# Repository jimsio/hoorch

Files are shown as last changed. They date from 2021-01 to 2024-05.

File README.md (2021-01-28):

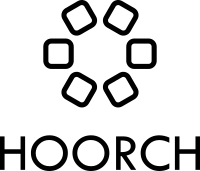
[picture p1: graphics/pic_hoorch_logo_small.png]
HOORCH Logo


an educational multimedia box

HOORCH is a multimedia box for primary school students. HOORCH is a dialect saying that means something like "listen up!".
It consists of a Raspberry Pi 3A+ , 6 RFID-Readers, a microphone, speakers and several LEDs and buttons. It is housed in a laser cutted box with a transparent board top.
We currently have 6 games:
* a storytelling game, where kids can record stories which are then stored for their specific character
* a calculating game
* a game for learning english animal names
* an animal voice guessing game
* an animal orchestra game for learning the animal voices
* a game for learning the parts of a modern instrumental song (e.g. bass line, hi-hat, snare, kick, melody)

Folders:
* . : python program, installation file (installer.sh), 
* [data](data): audio files
* [pcb](pcb): schematics, made with KiCad
* [graphics](graphics): laser cutter files for box, figures. vinylcutter files for cards, graphic files for animal stickers
* [docs](docs): documentation

HOORCH was developed at the University for Teacher Training (PH Wien) in Vienna, Austria.

Also visit our website:
(http://hoorch.phwien.ac.at)

# Installation

see [docs](docs)

# License

Licenced under the CC-BY-NC-SA 4.0 license

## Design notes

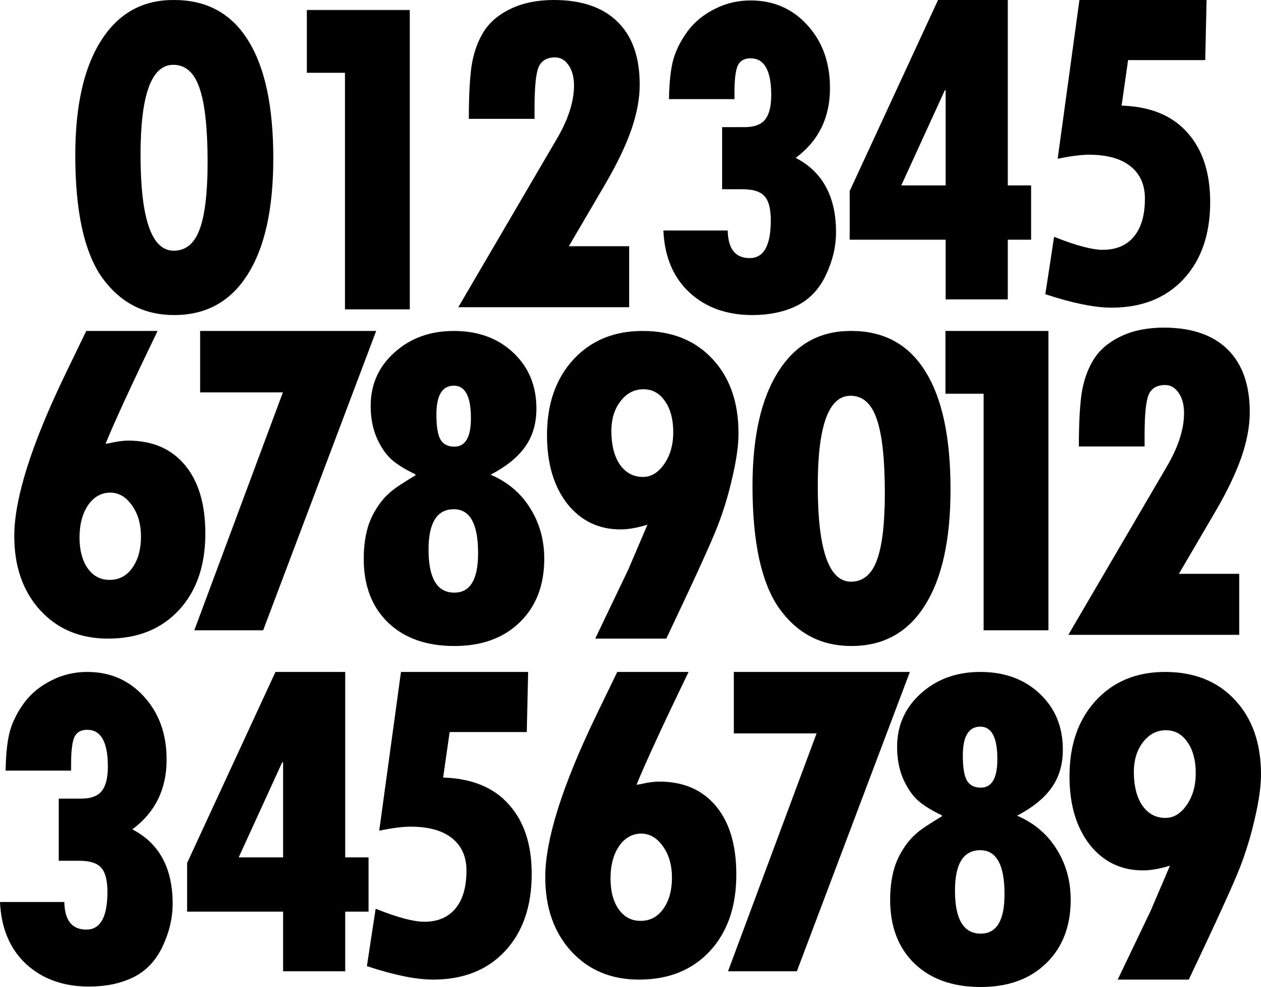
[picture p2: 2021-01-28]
graphics/vinyl_numbers.png

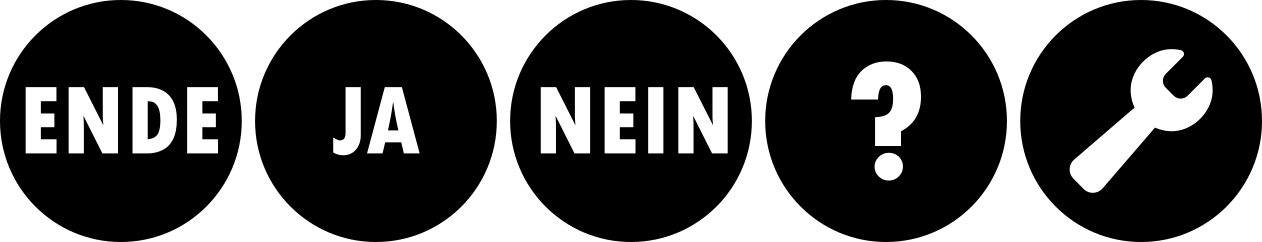
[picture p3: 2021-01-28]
graphics/vinyl_stickers.png

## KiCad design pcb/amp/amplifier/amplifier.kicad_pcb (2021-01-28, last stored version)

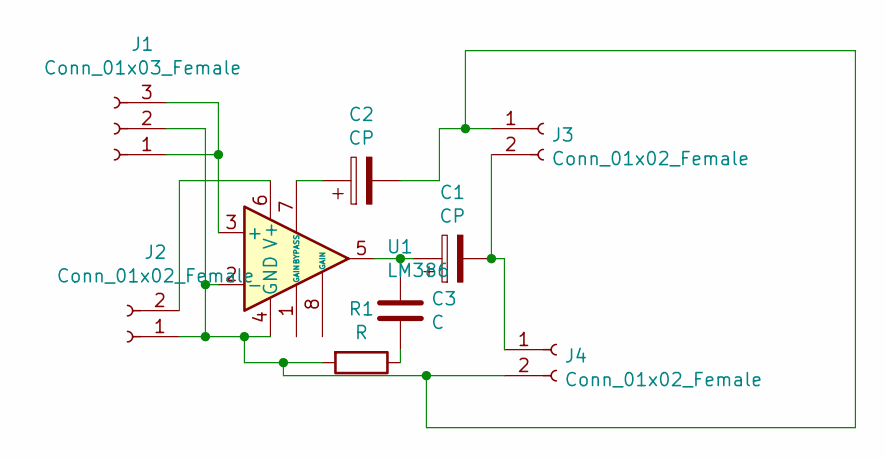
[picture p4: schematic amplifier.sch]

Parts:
C1: CP; CP_Radial_D10.0mm_P3.80mm
C2: CP; CP_Radial_D5.0mm_P2.50mm
C3: C; C_Disc_D4.3mm_W1.9mm_P5.00mm
J1: Conn_01x03_Female; PinHeader_1x03_P2.54mm_Vertical
J2, J3, J4: Conn_01x02_Female; PinHeader_1x02_P2.54mm_Vertical
R1: R; R_Axial_DIN0207_L6.3mm_D2.5mm_P10.16mm_Horizontal
U1: LM386; DIP-8_W7.62mm

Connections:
unnamed: C1.1, C3.1, U1.5
unnamed: C1.2, J3.2, J4.1
unnamed: C2.1, U1.7 (BYPASS)
unnamed: C2.2, J1.2, J2.1, J3.1, J4.2, R1.2, U1.2 (-), U1.4 (GND)
unnamed: C3.2, R1.1
unnamed: J1.1, J1.3, U1.3 (+)
unnamed: J2.2, U1.6 (V+)

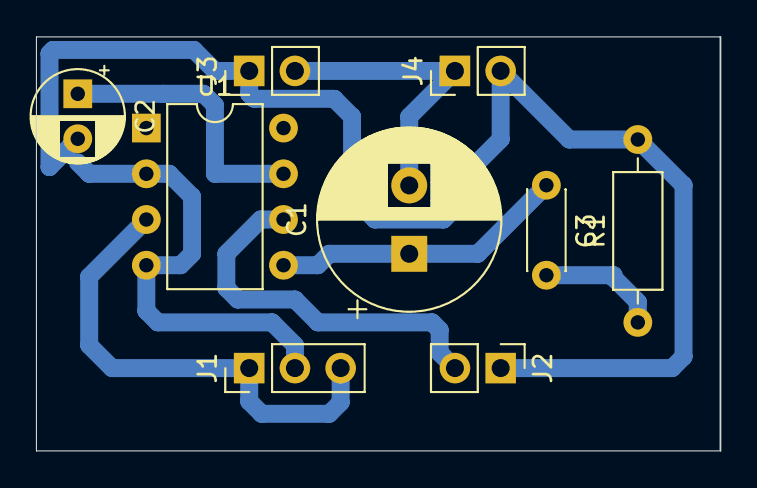
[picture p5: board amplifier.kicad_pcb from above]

Board: 2 copper layers, 38.0 x 23.0 mm, 9 parts (0 on the bottom side), 7 nets.

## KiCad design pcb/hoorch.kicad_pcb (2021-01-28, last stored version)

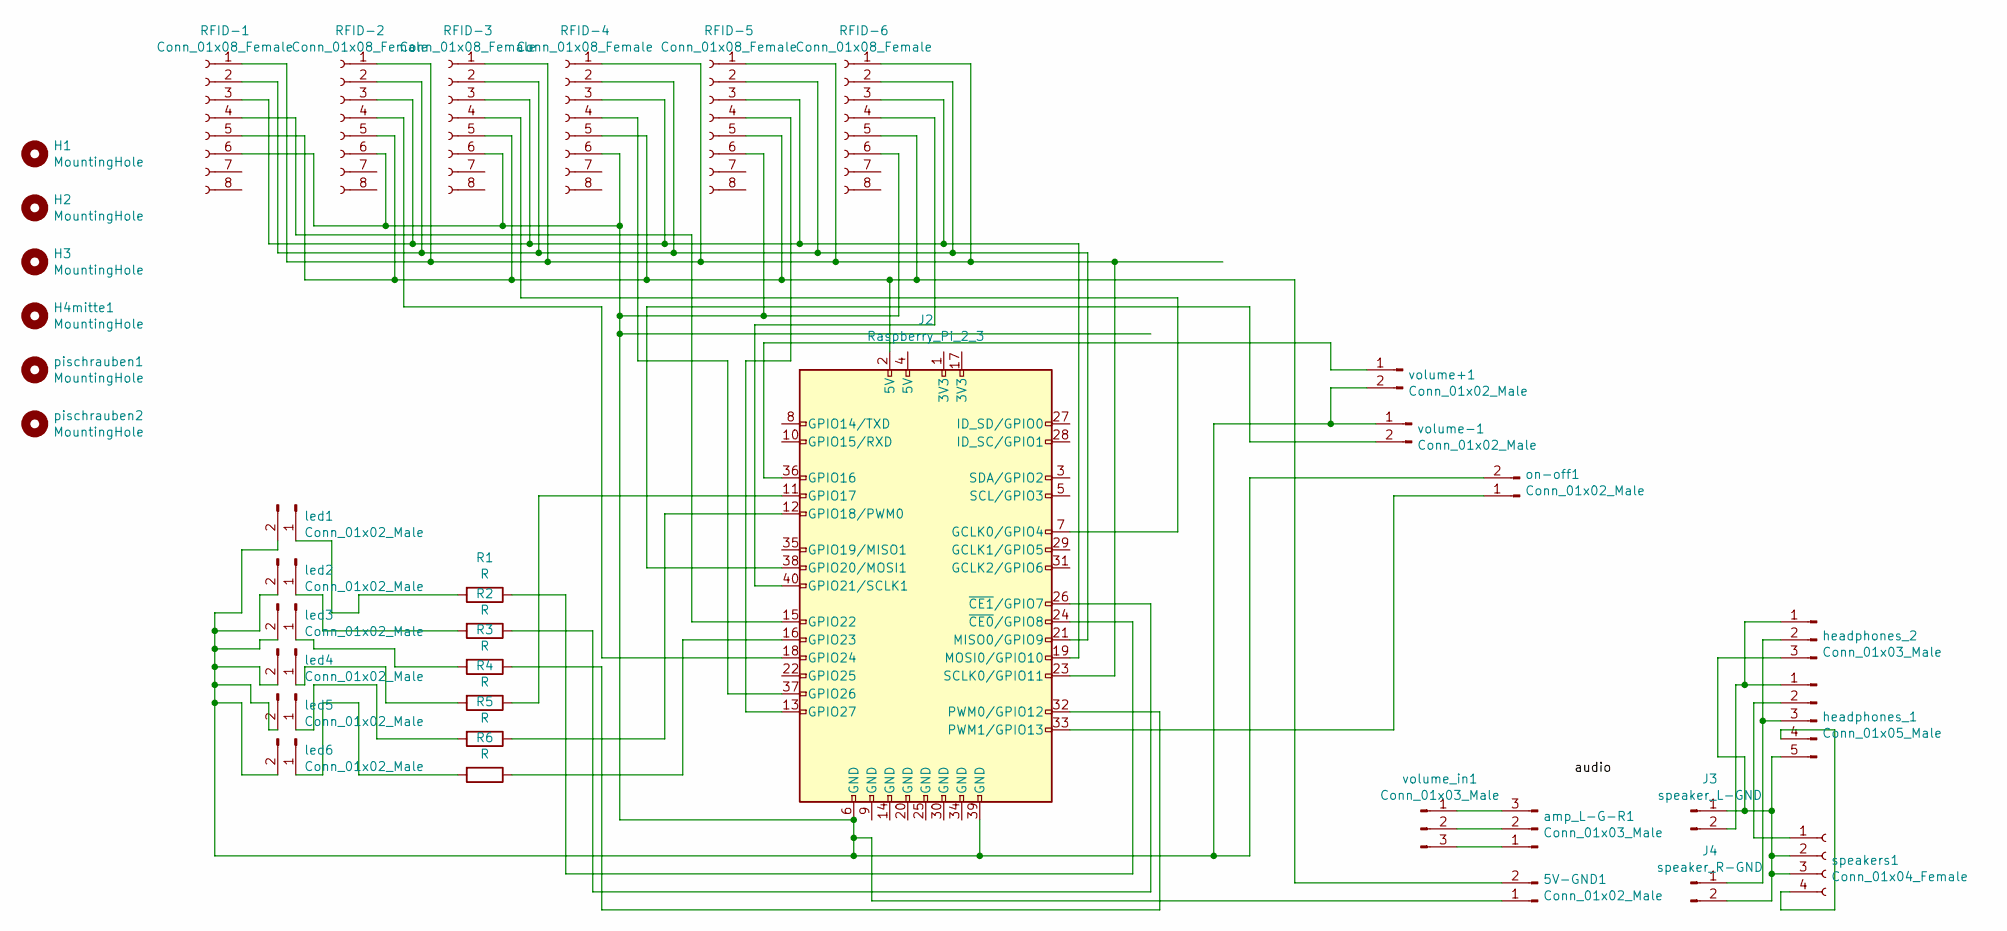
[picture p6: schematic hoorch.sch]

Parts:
5V-GND1: Conn_01x02_Male; PinHeader_1x02_P2.54mm_Vertical
H1, H2, H3: MountingHole; MountingHole_4.3mm_M4
H4mitte1: MountingHole; MountingHole_6.4mm_M6
J2: Raspberry_Pi_2_3; PinSocket_2x20_P2.54mm_Vertical
J3: speaker_L-GND; PinSocket_1x02_P2.54mm_Vertical
J4: speaker_R-GND; PinSocket_1x02_P2.54mm_Vertical
R1, R2, R3, R4, R5, R6: R; R_Axial_DIN0204_L3.6mm_D1.6mm_P5.08mm_Vertical
RFID-1, RFID-2, RFID-3, RFID-4, RFID-5, RFID-6: Conn_01x08_Female; PinSocket_1x08_P2.54mm_Vertical
amp_L-G-R1: Conn_01x03_Male; PinHeader_1x03_P2.54mm_Vertical
headphones_1: Conn_01x05_Male; PinHeader_1x05_P2.54mm_Vertical
headphones_2: Conn_01x03_Male; PinHeader_1x03_P2.54mm_Vertical
led1, led2, led3, led4, led5, led6: Conn_01x02_Male; PinSocket_1x02_P2.54mm_Vertical
on-off1: Conn_01x02_Male; PinSocket_1x02_P2.54mm_Vertical
pischrauben1, pischrauben2: MountingHole; MountingHole_3.2mm_M3
speakers1: Conn_01x04_Female; JST_EH_B04B-EH-A_1x04_P2.50mm_Vertical
volume+1: Conn_01x02_Male; PinSocket_1x02_P2.54mm_Vertical
volume-1: Conn_01x02_Male; PinSocket_1x02_P2.54mm_Vertical
volume_in1: Conn_01x03_Male; PinSocket_1x03_P2.54mm_Vertical

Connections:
unnamed: 5V-GND1.1, J2.6 (GND), J2.39 (GND), RFID-1.6, RFID-2.6, RFID-3.6, RFID-4.6, RFID-5.6, RFID-6.6, led1.2, led2.2, led3.2, led4.2, led5.2, led6.2, on-off1.2, volume+1.2, volume-1.1
unnamed: 5V-GND1.2, J2.2 (5V), RFID-1.5, RFID-2.5, RFID-3.5, RFID-4.5, RFID-5.5, RFID-6.5
unnamed: J2.7 (GCLK0/GPIO4), RFID-3.4
unnamed: J2.11 (GPIO17), R4.1
unnamed: J2.12 (GPIO18/PWM0), R5.1
unnamed: J2.13 (GPIO27), RFID-5.4
unnamed: J2.15 (GPIO22), RFID-1.4
unnamed: J2.16 (GPIO23), R6.1
unnamed: J2.18 (GPIO24), RFID-2.4
unnamed: J2.19 (MOSI0/GPIO10), RFID-1.3, RFID-2.3, RFID-3.3, RFID-4.3, RFID-5.3, RFID-6.3
unnamed: J2.21 (MISO0/GPIO9), RFID-1.2, RFID-2.2, RFID-3.2, RFID-4.2, RFID-5.2, RFID-6.2
unnamed: J2.23 (SCLK0/GPIO11), RFID-1.1, RFID-2.1, RFID-3.1, RFID-4.1, RFID-5.1, RFID-6.1
unnamed: J2.24 (~CE0~/GPIO8), R1.1
unnamed: J2.26 (~CE1~/GPIO7), R2.1
unnamed: J2.32 (PWM0/GPIO12), R3.1
unnamed: J2.33 (PWM1/GPIO13), on-off1.1
unnamed: J2.36 (GPIO16), volume+1.1
unnamed: J2.37 (GPIO26), RFID-4.4
unnamed: J2.38 (GPIO20/MOSI1), volume-1.2
unnamed: J2.40 (GPIO21/SCLK1), RFID-6.4
unnamed: J3.1, J4.2, headphones_1.5, headphones_2.3, speakers1.2, speakers1.3
unnamed: J3.2, headphones_1.1, headphones_2.1
unnamed: J4.1, headphones_1.3, headphones_2.2
unnamed: R1.2, led1.1
unnamed: R2.2, led2.1
unnamed: R3.2, led3.1
unnamed: R4.2, led4.1
unnamed: R5.2, led5.1
unnamed: R6.2, led6.1
unnamed: amp_L-G-R1.1, volume_in1.3
unnamed: amp_L-G-R1.2, volume_in1.2
unnamed: amp_L-G-R1.3, volume_in1.1
unnamed: headphones_1.2, speakers1.1
unnamed: headphones_1.4, speakers1.4

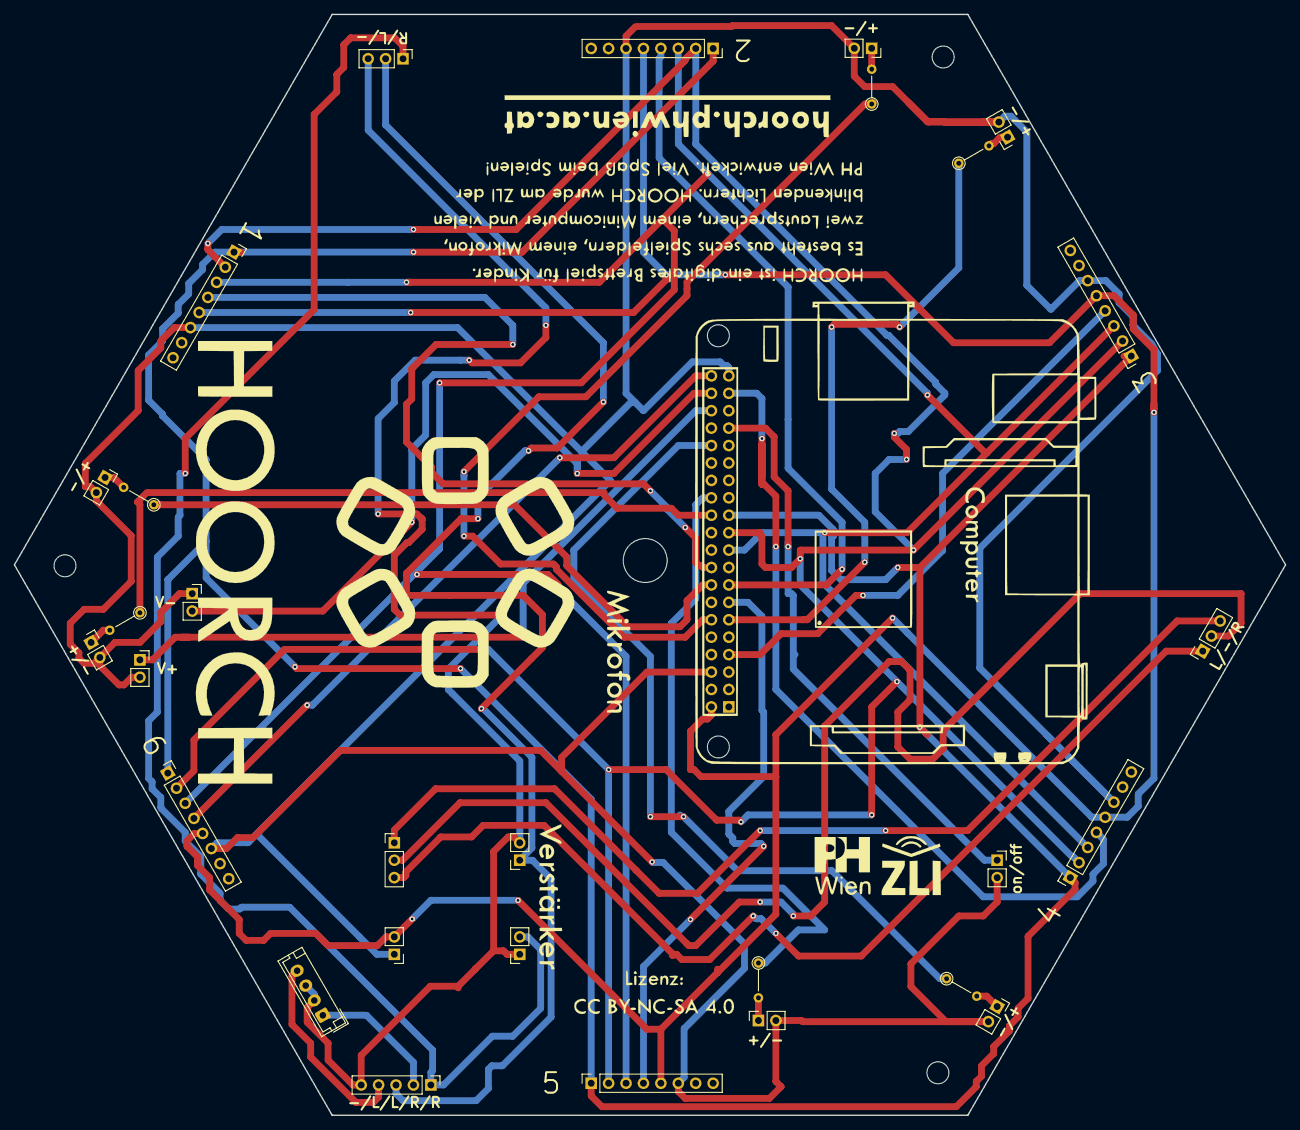
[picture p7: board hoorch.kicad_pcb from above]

Board: 2 copper layers, 185.3 x 160.5 mm, 36 parts (1 on the bottom side), 34 nets.

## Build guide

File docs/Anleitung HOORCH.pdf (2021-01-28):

1 | Version 1.0 | 08.10.2020

# HOORCH

## Kurzanleitung

HOORCH ist eine interaktive und multimediale Spiel-und-Lernbox für Kinder. Sie besteht aus einem Minicomputer, sechs RFID-Readern, einem Mikrofon, zwei Lautsprechern, vielen blinkenden Lichtern und bunten Tasten.

## HOORCH-Box und Zubehör

Zum HOORCH-Spieleset gehören:
- 1x HOORCH-Box aus Holz, Plexiglas und elektronischen Bauteilen
- 1x Stromkabel
- 2x Zubehör-Boxen mit:
- 20 KARTEN mit Tierbildern + Zahlen (Vorder- und Rückseite)
- 6x Holz-SPIELFIGUREN (Roboter, Ritter, Frau, Zauberer, König, Königin)
- 30x Grundplatte zum Ankleben von selbstgemachten Spielfiguren
- 7x Holz-SPIELAUSWAHLSTEINE (1x1, Orchester, Tierlaute,...)
- 5x Holz-FUNKTIONSSTEINE zur Spielsteuerung (JA, NEIN, ENDE, PAUSE, FRAGEZEICHEN)
- (2x Plexiglas-Funktionssteine für die Wartung für LehrerInnen (ADMIN, WIFI))

## Spiele

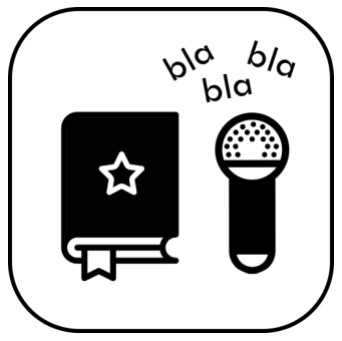
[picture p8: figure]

Geschichten aufnehmen:
Zu deiner Spielfigur kannst du in diesem Spiel eine Geschichte aufnehmen. Eine Spielfigur kann immer nur eine Geschichte speichern. Die alten Geschichten wandern bei einer neuen Aufnahme ins Archiv (auf das bald die LehrerInnen zugreifen können)

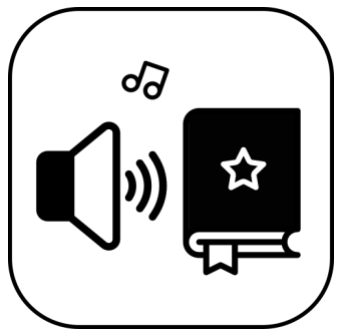
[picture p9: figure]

Geschichten abspielen:
Zuvor aufgenommene Geschichten können hier angehört werden.

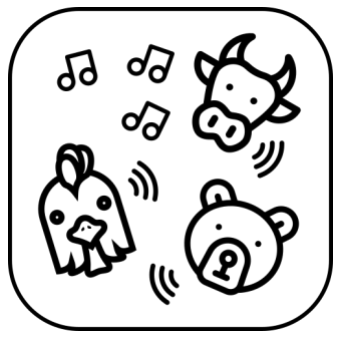
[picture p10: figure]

Tier-Orchester:
Lege die Tierkarten auf die Spielfelder und HOORCH spielt dir die passenden Tierlaute ab.

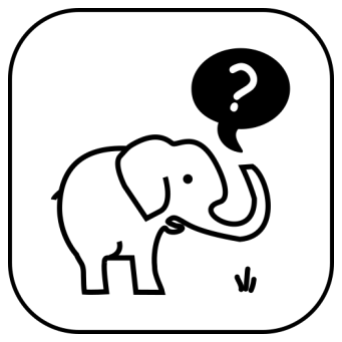
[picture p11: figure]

Tierlaute erraten:
In diesem Spiel können bis zu 6 SpielerInnen gegeneinander antreten und zu den abgespielten Tiernamen die richtigen Karten auf ihr Spielfeld legen.

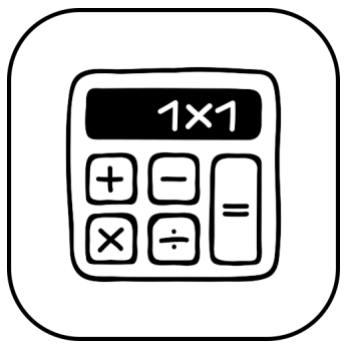
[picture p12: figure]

EinMalEins:
Bis zu drei SpielerInnen treten gegeneinander an und versuchen Rechnungen des kleinen EinMalEins zu lösen.
Wichtig: Links von deiner Figur wird die Zehnerstelle, rechts davon die Einerstelle hingelegt.

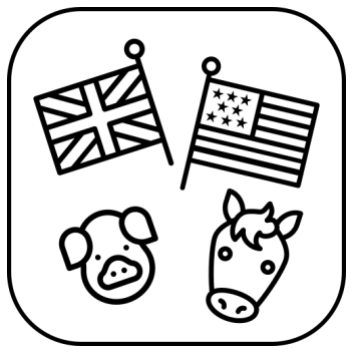
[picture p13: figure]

Animals in English:
In diesem Spiel kann man sowohl die englischen Tiernamen üben als auch in einem Spiel gegeneinander erraten.

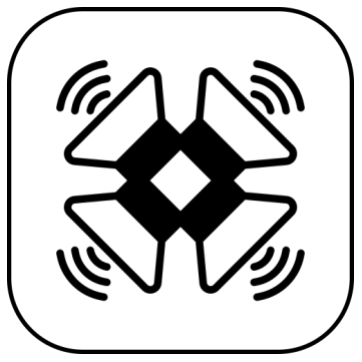
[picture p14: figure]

Kakophonie:
Spielerisch werden in diesem Spiel die Bestandteile eines modernen Songs erlernt. Lege die Zahlen von 1-6 auf die Felder und es werden von Melodie, Bass-Line bis Snare und Kickdrum die unterschiedlichsten Audio-Spuren eines Liedes abgespielt.

## Spielvorbereitung

Bevor du mit dem Spielen beginnst, treffe folgende Vorbereitungen:
1. Packe die HOORCH-Box und das Zubehör aus.
2. Sortiere die STEINE und FIGUREN in folgenden Gruppen: FUNKTIONSSTEINE, SPIELAUSWAHLSTEINE, SPIELFIGUREN, TIER- UND ZIFFERNKARTEN.
3. Jedes Kind wählt eine der 6 Spielfiguren: Roboter, Ritter, Frau, Zauberer, König, Königin. Es können höchstens 6 Kinder mitspielen.

Um HOORCH zu starten, schließe das Stromkabel an und betätige den Einschaltknopf. HOORCH startet jetzt. Mit dem FRAGEZEICHEN-Stein kannst du dir dann das Spiel kurz erklären lassen oder mit einem SPIELAUSWAHLSTEIN eines der Spiele starten.

## Hinweise zur Bedienung

Die HOORCH-Box spricht mit dir und erklärt dir jeweils den nächsten Schritt direkt während des Spielens, so dass die Spiele eigentlich selbsterklärend sind. Folgende Hinweise erklären die grundsätzliche Bedienung von HOORCH.

Mit den beiden großen Knöpfen auf der Seite kannst du durch Drücken die Lautstärke regeln: MINUS (-) ist eine Stufe leister, PLUS (+) ist eine Stufe lauter.

Der große blaue Knopf auf der Seite ist der Ausschaltknopf. Wenn du nicht mehr spielen willst, musst du diesen drei Sekunden gedrückt halten, bis HOORCH sagt, dass es sich jetzt ausschaltet. Wenn kein Lämpchen mehr leuchtet kannst du den Stromstecker ziehen.

Links und rechts befinden sich zwei Lautsprecher sowie zwei Buchsen für externe Kopfhörer. Wenn du Kopfhörer dort ansteckst, wo sich die Buchse mit dem Lautsprecher-AUS-Symbol befindet, dann ist die Box über die eingebauten Lautsprecher nicht mehr zu hören, sondern nur noch über die Kopfhörer. Das ist praktisch, wenn du andere durch dein Spielen nicht stören willst.

Oben in der Mitte der Plexiglasplatte befindet sich das Mikrofon. Wenn du bei einem Spiel aufgefordert wirst, etwas aufzunehmen, dann solltest du möglichst nah am Mikrofon laut und deutlich sprechen. Auch wenn du Geräusche aufnimmst, sollten die möglichst nah am Mikrofon sein.

Für das Spielen am wichtigsten sind die sechs Felder oben auf der Plexiglasplatte; dort kannst du Steine drauflegen oder Figuren draufstellen. Unter den sechs Feldern liegen die sogenannten RFID-Reader, mit denen du eine Aktion auslösen kannst. Je nachdem, was du auf ein solches Feld legst, macht die HOORCH-Box unterschiedliche Dinge:

- Mit dem JA-Stein beantwortest du eine Frage der HOORCH-Box mit Ja.
- Mit dem NEIN-Stein beantwortest du eine Frage der HOORCH-Box mit Nein.
- Mit dem ENDE-Stein beendest du das laufende Spiel und kannst anschließend zu einem anderen Spiel wechseln.

- Mit den SPIELAUSWAHLSTEINEN kannst du eines der Spiele auswählen und starten.
- MIt den SPIELFIGUREN unterscheidet die Box, wer gerade dran ist.
- TIER- und ZIFFERNKARTEN kommen bei den jeweiligen Spielen zum Einsatz.

Oft ist es so, dass es egal ist, auf welches Feld du einen Stein legst oder eine Figur stellst. Manchmal sagt dir die Box aber genau, welches Feld zu wählen ist, nämlich entweder durch Blinken des Feldes oder durch die Nummer des Feldes (von 1 bis 6).

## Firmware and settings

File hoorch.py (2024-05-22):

#!/usr/bin/env python3
# -*- coding: UTF8 -*-

# require: see installer.sh
import os
import time
import subprocess
import audio
import rfidreaders
import leds
import game_tierlaute
import game_geschichten_aufnehmen
import game_kakophonie
import game_tier_orchester
import game_geschichten_abspielen
import game_einmaleins
import game_animals_english
import game_hoerspiele
import game_aufnehmen
import admin
import tagwriter


def init():
    print("initializiation of hardware")

    # initialize audio
    audio.init()

    audio.play_full("TTS", 1)

    # initialize leds
    leds.init()

    # start random blinker
    #leds.blink = True

    # initialize readers
    rfidreaders.init()
    
    # initialize figure_db if no tags defined for this hoorch set
    if not os.path.exists("./figure_db.txt"):
        # tell the ip adress
        output = None
        while True:
            output = subprocess.run(
                ['hostname', '-I'], stdout=subprocess.PIPE, check=False).stdout.decode('utf-8')

            if output is None or output == '\n':
                audio.espeaker("WeiFei nicht verbunden")
                time.sleep(1.00)
                #if connected to router but internet on router is down, we need to open 
                # comitup-cli and and delete connection with d and establish a new one

            else:
                break

        ip_adress = output.split(" ", 1)
        audio.espeaker("Die eipi Adresse lautet")
        audio.espeaker(ip_adress[0])

        initial_hardware_test()

        rfidreaders.read_continuously = False
        time.sleep(1)
        tagwriter.write_set()
        rfidreaders.read_continuously = True
        rfidreaders.continuous_read()


def initial_hardware_test():
    # test run to check hardware on first hoorch start - will test leds, readers, speakers, microphone
    #leds.blink = False

    audio.espeaker("Jetzt wird die ganze Hardware getestet")

    audio.espeaker("Jetzt werden alle LEDs beleuchtet.")
    ## leds.rainbow_cycle(0.001)
    leds.rainbow_cycle(0.01)

    audio.espeaker("Wir testen jetzt die Ar ef eidi Leser.")
    for i in range(6):
        leds.switch_on_with_color(i, (255, 0, 0))
        audio.espeaker(f"Lege eine Karte auf Leser {i+1}")
        while True:
            if rfidreaders.tags[i] is not None:
                break

    leds.reset()

    audio.espeaker(
        "Ich teste jetzt das Audio, die Aufnahme beginnt in 3 Sekunden und dauert 6 Sekunden")
    time.sleep(3)
    leds.switch_all_on_with_color()
    
    # switch off speakers to avoid clicking
    audio.amp_sd.value = False

    print("aufnahme starten")
    subprocess.Popen("AUDIODEV=dmic_sv rec -c 1 ./data/figures/test/test.aif",
                     shell=True, stdout=None, stderr=None)
    time.sleep(6)
    #leds.rotate_one_round(6)
    print("aufnahme beendet")
    subprocess.Popen("killall rec", shell=True, stdout=None, stderr=None)

    leds.reset()

    # switch on speakers
    audio.amp_sd.value = True

    if os.path.exists("./data/figures/test/test.aif"):
        audio.espeaker("Ich spiele dir jetzt die Geschichte vor")
        leds.switch_all_on_with_color()
        audio.play_file("figures/test", "test.aif")
        time.sleep(7)
        leds.reset()
    else:
        audio.espeaker("Aufnahme hat nicht geklappt. Audio nicht gefunden")

    audio.espeaker("Test abgeschlossen.")


def main():
    print("start main loop")
    shutdown_time = 300  # seconds until shutdown if no interaction happened
    shutdown_counter = time.time()+shutdown_time

    greet_time = time.time()

    while True:
    #while shutdown_counter > time.time():

        leds.blink = True

        if greet_time < time.time():
            audio.play_full("TTS", 2)  # Welches Spiel wollt ihr spielen?
            greet_time = time.time()+30

        # Erklärung
        if "FRAGEZEICHEN" in rfidreaders.tags:
            print("Hoorch Erklärung")
            leds.blink = False
            audio.play_full("TTS", 65)  # Erklärung
            shutdown_counter = time.time()+shutdown_time

        # Games
        if "Aufnehmen" in rfidreaders.tags:
            print("Geschichten aufnehmen")
            leds.blink = False
            game_geschichten_aufnehmen.start()
            audio.play_full("TTS", 54)  # Das Spiel ist zu
            shutdown_counter = time.time()+shutdown_time

        if "Abspielen" in rfidreaders.tags:
            print("Geschichte abspielen")
            leds.blink = False
            game_geschichten_abspielen.start()
            audio.play_full("TTS", 54)  # Das Spiel ist zu Ende
            shutdown_counter = time.time()+shutdown_time

        if "Tierlaute" in rfidreaders.tags:
            print("Tierlaute erkennen")
            leds.blink = False
            game_tierlaute.start()
            audio.play_full("TTS", 54)  # Das Spiel ist zu Ende
            shutdown_counter = time.time()+shutdown_time

        if "TierOrchester" in rfidreaders.tags:
            print("Tier-Orchester")
            leds.blink = False
            game_tier_orchester.start()
            audio.play_full("TTS", 54)  # Das Spiel ist zu Ende
            shutdown_counter = time.time()+shutdown_time

        if "Kakophonie" in rfidreaders.tags:
            print("Kakophonie")
            leds.blink = False
            game_kakophonie.start()
            audio.play_full("TTS", 54)  # Das Spiel ist zu Ende
            shutdown_counter = time.time()+shutdown_time

        if "Einmaleins" in rfidreaders.tags:
            print("Einmaleins")
            leds.blink = False
            game_einmaleins.start()
            audio.play_full("TTS", 54)  # Das Spiel ist zu Ende
            shutdown_counter = time.time()+shutdown_time

        if "Animals" in rfidreaders.tags:
            print("Animals")
            leds.blink = False
            game_animals_english.start()
            audio.play_full("TTS", 54)  # Das Spiel ist zu Ende
            shutdown_counter = time.time()+shutdown_time
       
        #list of available hoerspiele without file extension - i.e. ['mutigTR', 'mutigDE', 'mutigHR']
        hoerspiele_list = [os.path.splitext(h)[0] for h in os.listdir("./data/hoerspiele/")]
        detected_hoerspiel_card = [i for i in hoerspiele_list if i in rfidreaders.tags]
          
        if detected_hoerspiel_card:
            print("Hoerspiele")
            leds.blink = False
            game_hoerspiele.start("hoerspiele/", detected_hoerspiel_card[0])
            shutdown_counter = time.time()+shutdown_time
       
        figure_dir = "./data/figures/"
        #get only folders, not files
        figure_dirs = [name for name in os.listdir(figure_dir) if os.path.isdir(os.path.join(figure_dir, name))]
        #list of available figures with a recording
        figure_with_recording = [k for k in figure_dirs if f"{k}.mp3" in os.listdir(figure_dir+k)]
        detected_figure_with_recording = [j for j in figure_with_recording if j in rfidreaders.tags]

        #all defined figure minus the ones with a recording
        defined_figures = rfidreaders.gamer_figures
        figure_without_recording = [i for i in defined_figures if i not in figure_with_recording]
        detected_figure_without_recording = [m for m in figure_without_recording if m in rfidreaders.tags]

        #prioritize figures with recordings over the ones without
        if detected_figure_with_recording:
            print("Geschichte abspielen - from main menu")
            leds.blink = False
            #pick first figure detected
            game_hoerspiele.start(f"figures/{detected_figure_with_recording[0]}", detected_figure_with_recording[0])
            shutdown_counter = time.time()+shutdown_time
        

        if detected_figure_without_recording:
            print("Geschichte aufnehmen - from main menu")
            leds.blink = False
            game_aufnehmen.start(detected_figure_without_recording[0])
            shutdown_counter = time.time()+shutdown_time

        # if "JA" and "NEIN" chips detected enter admin menu
        if "JA" in rfidreaders.tags and "NEIN" in rfidreaders.tags:
            admin.main()
            shutdown_counter = time.time()+shutdown_time

        time.sleep(0.3)

    # shutdown
    print("shutdown")
    # Du hast mich lange nicht verwendet. Ich schalte mich zum Stromsparen jetzt aus.
    audio.play_full("TTS", 196)
    leds.blink = False
    leds.led_value = [1, 1, 1, 1, 1, 1]
    # os.system("shutdown -P now")


if __name__ == "__main__":
    init()
    main()
    

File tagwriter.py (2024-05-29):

#!/usr/bin/env python3
# -*- coding: UTF8 -*-

import sys
import time
import unicodedata
import board
import busio
from adafruit_pn532.spi import PN532_SPI
from adafruit_pn532.adafruit_pn532 import MIFARE_CMD_AUTH_B
from digitalio import DigitalInOut
import ndef
import leds
import audio

# gpio24
reader1_pin = DigitalInOut(board.D24)

reader = []

spi = busio.SPI(board.SCK, board.MOSI, board.MISO)

reader.append(PN532_SPI(spi, reader1_pin, debug=False))
# ic, ver, rev, support = reader[0].firmware_version
reader[0].SAM_configuration()

path = "./figure_ids.txt"
file = open(path, mode="r", encoding="utf-8")
figures = file.readlines()
file.close()

figure_database = []

#to write to block 1 and 2 to mifare cards+chips
#14:01:03:E1:03:E1:03:E1:03:E1:03:E1:03:E1:03:E1
#03:E1:03:E1:03:E1:03:E1:03:E1:03:E1:03:E1:03:E1
mifare_block1_2 = b'\x14\x01\x03\xE1\x03\xE1\x03\xE1\x03\xE1\x03\xE1\x03\xE1\x03\xE1\x03\xE1\x03\xE1\x03\xE1\x03\xE1\x03\xE1\x03\xE1\x03\xE1\x03\xE1'

prefix = b'\x03'
#length_ndef_msg = b''
#record_header = b'\xD1'
#length_rec_type_field = b'\x01'
#payload_length = b'\'
#record_type = b'\x54'
#encoding = b'\x02' #utf8 and length of language code
#language = b'\x65\x6E'
suffix = b'\xFE'

#testdata = b'\x00\x00\x03\x10\xd1\x0e\x54\x02enHallo\xfe'

#https://community.element14.com/challenges-projects/project14/nfc-rfid/b/blog/posts/nfc-badge---update-your-badge-with-your-smartphone---ndef-and-app
#x03 = TLV Block tag field - 0x03=NDEF message / prefix
#!12! = length of the NDEF message 12 = 18 Bytes )
#--ndef record starts here
#xD1 = record header 0xD1= Well-Known Record
#01 = length of record type field
#0E = payload length (OE = 14 Bytes)
#54 = Record Type 0x54=Text Record
#--- here starts the payload ---
#02 = encoding (UTF8) and length of language code (2 bytes)
#65+6E = language code (en) - others: 64+65 (de)
#66:72:61:6E:7A = text string
#--- end payload ---
#--ndef record ends here
#FE - Terminator Last TLV block / suffix

key = b'\xFF\xFF\xFF\xFF\xFF\xFF'

#switch on the amp
audio.amp_sd.value = True

#write single word to ntag2 (sticker) or mifare (cards, chips)
#max length of word is 20!
def write_single(word):
    
    leds.switch_on_with_color(0)
    
    print("Place tag on reader1. Will write this to tag: "+str(word))
    #audio.espeaker("Schreibe "+str(word) +
    #               " auf den Täg. Bitte Täg auf Spielfeld 1 platzieren")
    time.sleep(2)
    tag_uid = reader[0].read_passive_target(timeout=0.2)

    if tag_uid:
        # bytearray(b'\x04q\x1b\xea\xa0e\x80') #ntag2
        #print(tag_uid)

        id_readable = ""

        for counter, number in enumerate(tag_uid):
            if counter < 4:
                id_readable += str(number)+"-"
            else:
                id_readable = id_readable[:-1]
                break

        success = write_on_tag(tag_uid, word, id_readable)
        
        if id_readable.endswith("-"):
            id_readable = id_readable[:-1]

        if success:
            print("successfully wrote "+str(word)+" to tag")
            print("now writing to database")
            audio.espeaker("Schreiben erfolgreich, Füge Täg zu Datenbank hinzu")

            db_file = open('figure_db.txt', 'a')
            # 12-56-128-34;ritter
            db_file.write(id_readable+";"+word+"\n")
            db_file.close()
        else:
            print("error occured while writing, try again.")

    else:
        print("no tag on rfid reader")
        audio.espeaker(
            "Du hast keinen Täg auf das Spielfeld platziert. Täg wurde nicht beschrieben.")


def write_set():
    audio.espeaker(
        "Wir beschreiben das gesamte Spieleset. Stelle die Figuren bei Aufruf auf Spielfeld 1")
    leds.reset()  # reset leds
    leds.switch_on_with_color(0)

    for figure in figures:
        # remove /n at the end - file figure_ids.txt needs an empty line at the end
        figure = figure[:figure.find("\n")]

        if figure == "+":
            audio.espeaker("Nächster Abschnitt")
            figure_database.append(["", ""])
            continue

        else:
            success = False
            audio.espeaker("Nächster Figur:")
            audio.espeaker(figure)
            
            while not success:

                tag_uid = None
                
                audio.espeaker("Figur stehen lassen")

                while not tag_uid:
                    tag_uid = reader[0].read_passive_target(timeout=1.0)

                id_readable = ""

                for counter, number in enumerate(tag_uid):
                    if counter < 4:
                        id_readable += str(number)+"-"
                    else:
                        id_readable = id_readable[:-1]
                        break

                success = write_on_tag(tag_uid, figure, id_readable)

            if id_readable.endswith("-"):
                id_readable = id_readable[:-1]
                
            figure_database.append([id_readable, figure])
            print("added figure to figure db")

    leds.reset()
    audio.espeaker("Ende der Datei erreicht, schreibe die Datenbank")

    db_file = open('figure_db.txt', 'w')
    for pair in figure_database:
        # 12-56-128-34;ritter
        db_file.write(str(pair[0])+";"+str(pair[1])+"\n")

    db_file.close()
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

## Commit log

2020-09-28 1x1 : tens a unit leds blink
2021-01-28 added doc, pcb, graphics
    [amplifier.kicad_pcb, amplifier.sch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]
2021-04-22 remove power_down for saving energy, it seems to corrupt reading of some readers
2023-01-09 update for new pcb
2023-01-30 same as before
    [amplifier.kicad_pcb, amplifier.sch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]
2023-03-02 button debouncing added
2023-05-04 led and hostname addons
2023-05-04 aufnahme led test
2023-05-04 add wheel
2023-05-04 leds autowrite True
2023-05-04 aif test with led
2023-05-04 aif with leds
2023-05-04 speakers on no auto update leds
2023-05-04 led hoorch fix
2023-05-15 remove leds, for recording test
2023-05-15 added led again, test that.
2023-05-15 random timer to blink
2023-05-15 flickering because of too fast neopixel.show
    [leds.py]
2023-05-15 aufnahme switch all on with color
2023-05-15 update for new led functions
2023-10-12 rfidreaders sleep o avoid voltage drop
    [rfidreaders.py]
2023-10-12 rfidreaders threading timer 1.4
2023-10-12 add rotate leds 1x1
2023-10-12 leds off
2023-10-16 test led+recording
2023-10-16 test switch on with color while recording
2023-10-16 switch all on with color
2023-11-20 avoid simultaneous rfid-read and audio play
    [audio.py, rfidreaders.py]
2024-01-15 print data
2024-01-15 switch on amp
2024-01-18 print data mifare
2024-02-29 nfc out of range fix
    [rfidreaders.py, tagwriter.py]
2024-02-29 reader copy error fix
    [rfidreaders.py]
2024-02-29 tailing minus idreadable error fix
    [rfidreaders.py, tagwriter.py]
2024-02-29 fix tailing minus again
    [rfidreaders.py, tagwriter.py]
2024-04-08 removed power down, added webserver.service and install script
2024-04-22 led boost 0.9 brightness, espeaker fix elif rec-play from main menu
    [admin.py, audio.py, hoorch.py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]
2024-04-22 readers power down
2024-05-22 error handling rfid reading
    [rfidreaders.py]
2024-05-22 ndeflib error print
